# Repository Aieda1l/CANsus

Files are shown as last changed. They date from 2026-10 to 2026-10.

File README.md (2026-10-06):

# CANsus

**CANsus** ("CAN sustain") is an iterated CAN, power, and auxiliary-signal distribution PCB developed for **Newport Robotics Group (Team 948)**. The project evolved from a CAN-only terminal board into a compact, serviceable wiring hub with modular connectors, power distribution, status indication, and a documented hardware revision history.

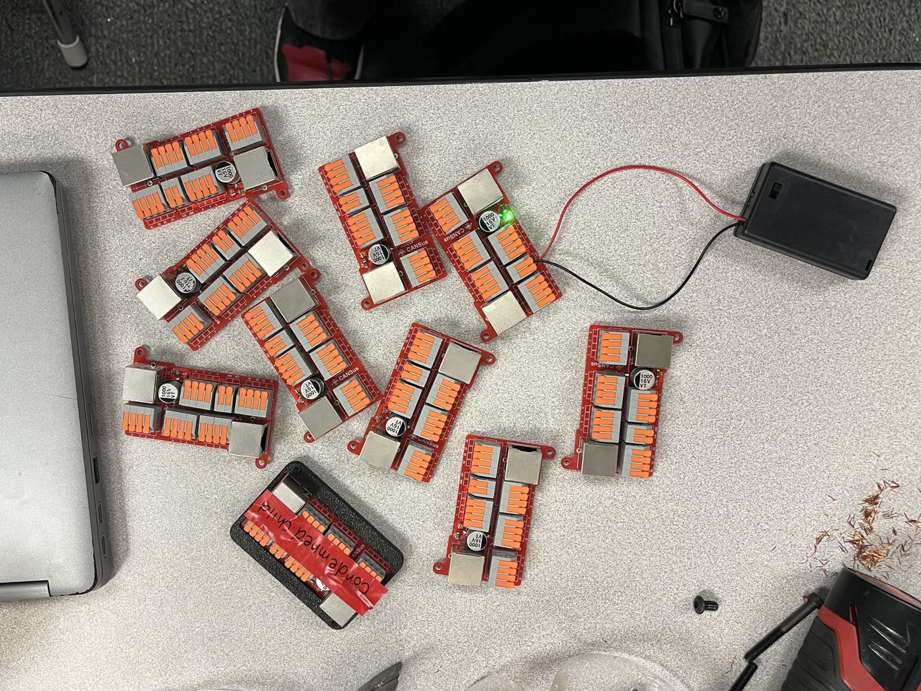
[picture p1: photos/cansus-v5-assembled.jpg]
CANsus assembled hardware


## Project overview

Robot electrical systems accumulate many point-to-point connections that must remain reliable, easy to diagnose, and practical to service under time pressure. CANsus explores a purpose-built distribution board for organizing those connections in a repeatable PCB assembly instead of relying only on loose in-line wiring.

The available KiCad history spans **v10 through v16** and shows several major design iterations: connector-family changes, board-size optimization, addition of power and auxiliary signals, migration of support components to SMD footprints, and simplification of the final interface.

This repository is intended to show not only the final hardware, but also the engineering iteration behind it.

## Engineering highlights

- **Seven documented KiCad revisions (v10-v16)** compared from the supplied design files.
- Progressed from **CAN-only distribution** to a combined **CAN + 12 V/GND + auxiliary-signal** interface.
- Added **dual RJ45 interfaces**, a bulk capacitor, and an LED status circuit beginning in v13.
- Reworked the terminal architecture in v14 from many 2-position blocks to larger **WAGO 2601-series multi-position connectors**.
- Reduced the v14 board envelope from approximately **86 × 53 mm** to **73.25 × 52.94 mm** in v15 while removing one redundant auxiliary connector — about a **14.8% reduction in width**.
- v16 simplifies the auxiliary interface from four signal nets to **two signal nets**, repurposing the remaining terminal capacity for 12 V and GND.
- The v16 layout uses **1.5 mm routing for 12 V/GND distribution** and **0.25 mm routing for CAN and auxiliary signals**.
- Physical board photos and a mechanical render document the transition from PCB design to assembled hardware.

> Revision details below are reconstructed directly from differences in the supplied KiCad schematic and PCB files. Where the files do not record the reason for a change, the documentation describes only the observed design change rather than inventing a rationale.

## Latest supplied electrical architecture — v16

The v16 design is a 2-layer, nominal 1.6 mm PCB with an Edge.Cuts envelope of approximately **73.25 × 52.94 mm**.

| Interface | Function |
|---|---|
| J1-J4 | WAGO 2601-1104 CAN distribution blocks; repeated CAN_HI / CAN_LO connections |
| J5 | WAGO 2601-1104 carrying SIGNAL_1, SIGNAL_2, 12 V, and GND |
| J7 | WAGO 2601-1102 carrying 12 V and GND |
| RJ1, RJ2 | 12 V, GND, SIGNAL_1, SIGNAL_2, CAN_HI, and CAN_LO; pins 5/6 are intentionally unconnected in v16 |
| C1 | Bulk capacitance across 12 V and GND |
| D1 + R1 | Power/status LED circuit |
| H1, H2 | #4-40 mounting holes |

The v16 RJ45 mapping visible in the PCB source is:

| Pin | Signal |
|---:|---|
| 1 | 12 V |
| 2 | GND |
| 3 | SIGNAL_1 |
| 4 | SIGNAL_2 |
| 5 | NC |
| 6 | NC |
| 7 | CAN_HI |
| 8 | CAN_LO |

## Design evolution

| Revision | Key change |
|---|---|
| **v10** | CAN-only baseline using 18 WAGO 250-202 two-position terminals and four mounting holes. |
| **v11** | Switched to WAGO 2601-3102 connectors, reduced the terminal count to 12, and narrowed the board. |
| **v12** | Reduced the CAN terminal count again to 10 and substantially compacted the board outline. |
| **v13** | Major functional expansion: added 12 V/GND, SIGNAL_1-SIGNAL_4, two RJ45 connectors, bulk capacitance, and an LED/resistor indicator circuit. |
| **v14** | Major connector/mechanical redesign: moved to 2601-1104/1102 terminal blocks, changed RJ45 footprint family, migrated the LED/resistor support circuitry to SMD footprints, and reduced mounting holes from four to two. |
| **v15** | Removed one duplicated auxiliary terminal block and reduced board width from 86 mm to 73.25 mm. |
| **v16** | Simplified the auxiliary interface to SIGNAL_1/SIGNAL_2; RJ45 pins 5/6 became NC and J5 was repurposed to include 12 V/GND. |

See [REVISION_LOG.md](REVISION_LOG.md) for the source-derived comparison and dimensional details.

## Hardware

### Assembled board

CANsus assembled hardware

The assembled-board photo shows multiple fabricated CANsus boards, lever terminals, modular connectors, the bulk capacitor, and an illuminated status LED.

### Mechanical / enclosure render

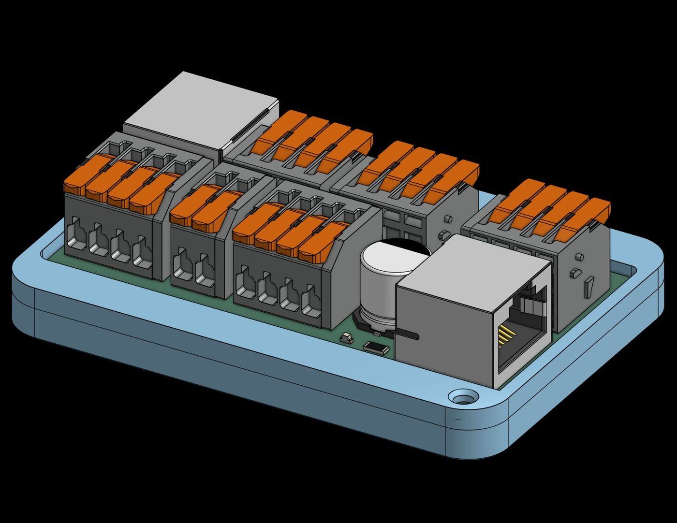
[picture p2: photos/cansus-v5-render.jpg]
CANsus render


### Earlier board

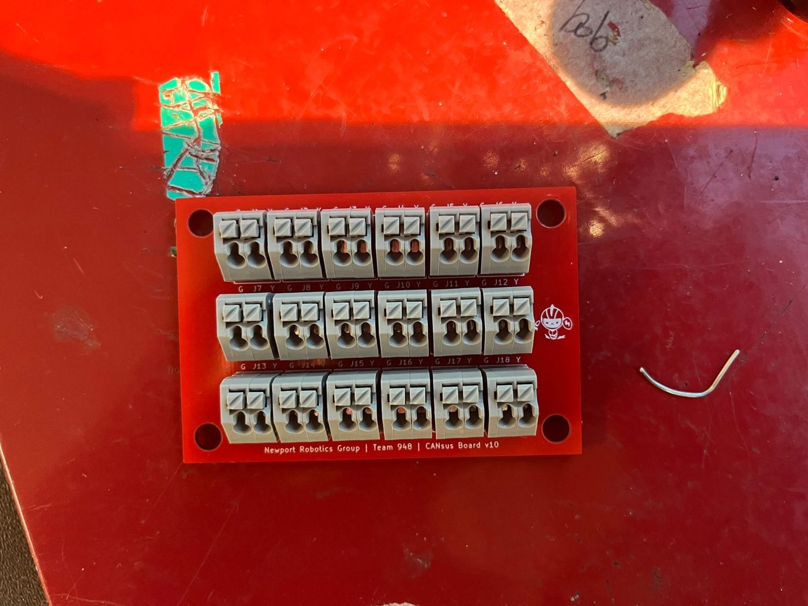
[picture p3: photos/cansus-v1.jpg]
Earlier CANsus board


The earlier photo visibly carries **CANsus Board v10** silkscreen. The photo filenames use a separate “Version 1 / Version 5” media-labeling scheme, so this repository treats the KiCad folder names (v10-v16) as the electrical design revision sequence.

## Repository contents

```text
.
├── LICENSE
├── README.md
├── REVISION_LOG.md
├── bom/
│   └── BOM.csv
├── docs/
│   ├── README.md
│   ├── cansus-board-layout.pdf
│   └── cansus-schematic.pdf
├── hardware/
│   └── kicad/
│       ├── CAN_board.kicad_pcb
│       ├── CAN_board.kicad_pro
│       ├── CAN_board.kicad_sch
│       ├── fp-lib-table
│       ├── sym-lib-table
│       └── README.md
└── photos/
    ├── cansus-v1.jpg
    ├── cansus-v5-assembled.jpg
    └── cansus-v5-render.jpg
```

## Reviewing the project

For a quick technical review:

1. Start with this README for the system architecture and design progression.
2. Read [REVISION_LOG.md](REVISION_LOG.md) for the v10-v16 hardware comparison.
3. Open the [KiCad source](hardware/kicad/) to inspect the schematic and routed PCB.
4. Review the [BOM](bom/BOM.csv) for component references.
5. Use the [PDF exports](docs/) and photos for a fast visual overview.

The browsable `hardware/kicad/` directory is the previously committed v15 source snapshot. The additional v10-v16 KiCad export set was used to reconstruct the revision history in this documentation. The supplied PDF exports also correspond to the four-signal v14/v15-era architecture; see [docs/README.md](docs/README.md).

## Tools and engineering scope represented

**KiCad 8 · schematic capture · PCB layout · connector/footprint selection · mixed through-hole/SMD design · mechanical packaging · hardware iteration · BOM/documentation · prototype assembly**

## Source notes

Some PCB 3D-model references use absolute paths from the original workstation, so a few models may be missing in KiCad's 3D viewer on another computer. The electrical schematic and PCB footprints are still embedded in the KiCad project files.

R1 is labeled simply `R` in the supplied schematic; its resistance value is therefore intentionally left unspecified in the BOM rather than guessed.

## License

Released under the [MIT License](LICENSE).

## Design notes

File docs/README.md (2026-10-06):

# PDF export notes

The PDFs in this directory are reference exports supplied with the project.

- `cansus-schematic.pdf` shows the four-auxiliary-signal architecture used by the v14/v15 design family: 12 V, GND, SIGNAL_1-SIGNAL_4, CAN_HI, CAN_LO, dual RJ45, and WAGO distribution blocks.
- `cansus-board-layout.pdf` is the accompanying PCB-layout export.

The later v16 KiCad source changes the auxiliary interface by removing SIGNAL_3 and SIGNAL_4, so these PDFs should be treated as **v14/v15-era reference exports**, not as a v16 electrical-interface definition.

For revision-by-revision differences, see [../REVISION_LOG.md](../REVISION_LOG.md).

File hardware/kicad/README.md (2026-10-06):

# KiCad source notes

The files in this directory are the **browsable v15 KiCad source snapshot** that was originally committed to the repository. A separate supplied export set containing v10-v16 was compared to build the source-derived [revision log](../../REVISION_LOG.md).

## Tool version

The supplied schematic and PCB files report **KiCad 8.0** generators.

## Files kept here

- `CAN_board.kicad_pro` — project settings
- `CAN_board.kicad_sch` — schematic
- `CAN_board.kicad_pcb` — PCB layout
- `fp-lib-table` — project footprint-library table
- `sym-lib-table` — project symbol-library table

Generated/local-state material such as `.history`, KiCad backups, `fp-info-cache`, and `.kicad_prl` is intentionally not committed.

## v15 snapshot architecture

This source snapshot contains:

- four 2601-1104 CAN distribution blocks (J1-J4)
- one 2601-1104 auxiliary block (J5) carrying SIGNAL_1-SIGNAL_4
- one 2601-1102 power block (J7) carrying 12 V/GND
- two RJ45 connectors carrying 12 V, GND, SIGNAL_1-SIGNAL_4, CAN_HI, and CAN_LO
- bulk capacitor C1
- 0603 LED D1
- 1206 resistor R1
- two #4-40 mounting holes

The later v16 export keeps the same board envelope and physical component count, but removes SIGNAL_3/SIGNAL_4 from the interface and repurposes part of J5 for 12 V/GND. See [REVISION_LOG.md](../../REVISION_LOG.md).

## Portability caveat

Some PCB 3D-model references point to absolute paths on the original designer's workstation, including local model paths for the RJ45, capacitor, and mechanical hardware. Those missing model paths do **not** change the copper or schematic source, but KiCad's 3D viewer may show missing models on another machine.

The schematic symbols and PCB footprints used by the design are embedded in the `.kicad_sch` and `.kicad_pcb` files, so the electrical/layout source remains inspectable even if an external library path is unavailable.

## Revision-label caveat

The historical folder names provide the most useful revision sequence. The PCB title blocks lag behind that sequence: v10-v13 carry a v10 title and v14-v16 carry a v14 title. The repository preserves the source as supplied rather than silently rewriting the title blocks.

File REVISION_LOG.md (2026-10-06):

# CANsus revision log

This revision history was reconstructed by comparing the supplied **KiCad v10-v16 schematic and PCB files**. The entries below document changes that are directly visible in the source: component/connector selection, net names and pin mappings, board outline, routing, and mounting features.

**Date note:** the dates shown are file-modification timestamps stored in the supplied KiCad export archive. They are useful for chronology, but they are not asserted to be formal release dates.

**Intent note:** the design files record *what changed*, not necessarily *why*. Where design intent is not explicitly encoded, this log avoids assigning a rationale.

## Summary

| Revision | Archive PCB timestamp | Edge.Cuts envelope | Main observed change |
|---|---|---:|---|
| v10 | 2024-06-05 | 76.20 × 50.80 mm | CAN-only baseline with 18 WAGO 250-202 terminal blocks |
| v11 | 2024-08-14 | 57.15 × 50.80 mm | Connector-family change to 2601-3102; terminal count reduced to 12 |
| v12 | 2024-08-16 | 63.50 × 33.02 mm | Terminal count reduced to 10; much shorter board |
| v13 | 2024-10-08 | 93.98 × 40.64 mm | Added 12 V/GND, four auxiliary signals, dual RJ45, bulk capacitor, LED/resistor |
| v14 | 2025-01-07 | 86.00 × 53.00 mm | Major connector/mechanical redesign; 2601-1104/1102 blocks, new RJ45s, SMD support parts |
| v15 | 2025-01-09 | 73.25 × 52.94 mm | Removed one auxiliary block and compacted board width |
| v16 | 2025-01-26 | 73.25 × 52.94 mm | Reduced auxiliary interface from four signals to two; repurposed J5 for power |

## v10 — CAN-only baseline

**Observed hardware**

- 18 × WAGO 250-202 two-position terminal footprints, J1-J18.
- Four mounting holes.
- Only two named electrical nets: `CAN_HI` and `CAN_LO`.
- Approximate board envelope: **76.20 × 50.80 mm**.
- Routed with 0.25 mm copper tracks in the supplied PCB.

This is the earliest KiCad snapshot in the supplied design history and matches the `CANsus Board v10` text visible on the earlier physical-board photo.

## v11 — connector-family and density change

**Changes from v10**

- Replaced the 250-202 connector family with **WAGO 2601-3102** footprints.
- Reduced the terminal population from **18 to 12** connector footprints.
- Mounting-hole footprints are represented as **#4-40 UNC** hardware in the PCB.
- Narrowed the board envelope from 76.20 mm to **57.15 mm** while retaining the 50.80 mm height.
- Electrical scope remained CAN-only: `CAN_HI` and `CAN_LO`.

## v12 — further CAN-only compaction

**Changes from v11**

- Reduced the 2601-3102 terminal population from **12 to 10**.
- Retained four #4-40 mounting holes.
- Continued to expose only `CAN_HI` and `CAN_LO`.
- Changed the board envelope to approximately **63.50 × 33.02 mm**, substantially reducing height relative to v11.

## v13 — major functional expansion

v13 is the first supplied revision that expands CANsus beyond a CAN-only distribution board.

**Added electrical functions**

- `12V`
- `GND`
- `SIGNAL_1`
- `SIGNAL_2`
- `SIGNAL_3`
- `SIGNAL_4`

**Added hardware**

- Two **SS-7188-NF RJ45** connectors, J11 and J12.
- Bulk polarized capacitor C1 between 12 V and GND.
- Through-hole LED D1 and resistor R1 as a status/power indicator circuit.
- Additional 2601-3102 terminal blocks for power and auxiliary-signal distribution.

**RJ45 mapping in v13**

| Pin | Signal |
|---:|---|
| 1 | SIGNAL_4 |
| 2 | GND |
| 3 | SIGNAL_3 |
| 4 | 12 V |
| 5 | CAN_LO |
| 6 | SIGNAL_2 |
| 7 | CAN_HI |
| 8 | SIGNAL_1 |

**Layout changes**

- Board envelope increased to approximately **93.98 × 40.64 mm** to accommodate the expanded interface.
- 12 V and GND routing uses **1.5 mm traces** in the supplied layout; CAN and signal routing remains primarily 0.25 mm.

## v14 — major architecture and packaging redesign

v14 substantially reorganizes the connector layout while retaining the expanded v13 signal set.

**Changes from v13**

- Replaced the many 2601-3102 terminal blocks with:
  - 6 × **WAGO 2601-1104** four-position blocks.
  - 1 × **WAGO 2601-1102** two-position block.
- Replaced the SS-7188-NF RJ45 footprints with **R-RJ45R08P-B000** connectors.
- Changed C1 to the `VT1C102M1010` footprint/value used in the later revisions.
- Migrated D1 from a through-hole LED footprint to **0603 SMD**.
- Migrated R1 from a through-hole resistor footprint to **1206 SMD**.
- Reduced mounting holes from **four to two** #4-40 holes.
- Board envelope became approximately **86.00 × 53.00 mm**.

**Functional grouping**

- J1-J4 provide repeated CAN_HI / CAN_LO distribution.
- J5 and J6 each duplicate SIGNAL_1-SIGNAL_4.
- J7 provides 12 V and GND.
- Both RJ45 connectors carry 12 V, GND, four auxiliary signals, CAN_HI, and CAN_LO.

**RJ45 mapping in v14**

| Pin | Signal |
|---:|---|
| 1 | 12 V |
| 2 | GND |
| 3 | SIGNAL_1 |
| 4 | SIGNAL_2 |
| 5 | SIGNAL_3 |
| 6 | SIGNAL_4 |
| 7 | CAN_HI |
| 8 | CAN_LO |

## v15 — compacted four-signal layout

**Changes from v14**

- Removed J6, one of the two duplicated 2601-1104 auxiliary-signal blocks.
- Retained J5 for SIGNAL_1-SIGNAL_4.
- Retained four 2601-1104 CAN distribution blocks, the 2601-1102 12 V/GND block, and both RJ45 connectors.
- Reduced board width from **86.00 mm to 73.25 mm**, approximately **14.8% narrower**.
- Board height remained essentially unchanged at about 52.94 mm.
- The PCB logo footprint changed to a half-size variant.
- Routing was substantially reworked; the net set and RJ45 pinout remained the same as v14.

The schematic/PCB PDF exports currently stored in `docs/` correspond to this four-auxiliary-signal architecture.

## v16 — simplified auxiliary interface

v16 keeps the v15 mechanical envelope and component count but changes the electrical assignment of the auxiliary interface.

**Changes from v15**

- Removed the named nets `SIGNAL_3` and `SIGNAL_4`.
- RJ1/RJ2 pins 5 and 6 changed from SIGNAL_3 / SIGNAL_4 to **unconnected**.
- J5 was repurposed:
  - pins 1/2: SIGNAL_1
  - pins 3/4: SIGNAL_2
  - pins 5/6: 12 V
  - pins 7/8: GND
- J7 remains a dedicated 12 V/GND connector.
- CAN distribution on J1-J4 remains unchanged.
- Board envelope remains approximately **73.25 × 52.94 mm**.
- Routing was adjusted to support the new net assignment.
- 12 V/GND continue to use 1.5 mm routing for the main distribution paths; CAN and auxiliary signal traces are 0.25 mm in the supplied PCB.

**v16 RJ45 mapping**

| Pin | Signal |
|---:|---|
| 1 | 12 V |
| 2 | GND |
| 3 | SIGNAL_1 |
| 4 | SIGNAL_2 |
| 5 | NC |
| 6 | NC |
| 7 | CAN_HI |
| 8 | CAN_LO |

## Revision-label notes

The project contains multiple forms of version labeling:

- The historical KiCad export folders are named **v10 through v16**. This log uses those folder names as the revision sequence.
- PCB title blocks are not consistently updated: v10-v13 still show `CANSus Board v10`, while v14-v16 show `CANSus Board v14`.
- The physical-photo filenames use a separate `Version 1` / `Version 5` naming scheme. The earlier photo visibly shows v10 silkscreen, so those photo names are treated as media labels rather than electrical revision numbers.

Keeping those distinctions explicit avoids rewriting the historical source or assigning unsupported mappings between the naming schemes.

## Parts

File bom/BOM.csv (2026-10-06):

Quantity | References | Value / Part | Footprint | Datasheet / Source | Notes
5 | J1, J2, J3, J4, J5 | 2601-1104 | 2601-1104:CONN4_2601-1104_WAG | 2601-1104 | WAGO four-position connector; exact manufacturer metadata not embedded beyond part number
1 | J7 | 2601-1102 | 2601-1102:CONN2_2601-1102_WAG | 2601-1102 | WAGO two-position connector; exact manufacturer metadata not embedded beyond part number
2 | RJ1, RJ2 | R-RJ45R08P-B000 | easyeda2kicad:RJ45-TH_R-RJ45R08P-B000 | https://lcsc.com/product-detail/Ethernet-Connectors-Modular-Connectors-RJ45-RJ11_Shenzhen-Cankemeng-R-RJ45R08P-B000_C386756.html | Through-hole RJ45 modular connector
1 | R1 | R | Resistor_SMD:R_1206_3216Metric | ~ | Resistance value is not specified in the supplied schematic
1 | C1 | VT1C102M1010 | easyeda2kicad:CAP-SMD_BD10.0-L10.3-W10.3-LS11.3-FD | https://lcsc.com/product-detail/Others_ROQANG-VT1C102M1010_C310843.html | Bulk capacitor as specified by schematic value
1 | D1 | LED | LED_SMD:LED_0603_1608Metric | ~ | 0603 indicator LED; color/part number not specified in the supplied schematic
2 | H1, H2 | MountingHole_#4-40_UNC_3A | MountingHole_Imperial:MountingHole_#4-40_UNC_3A | https://www.mcmaster.com/products/screws/ | Mechanical mounting holes; listed for completeness, not a purchased PCB component

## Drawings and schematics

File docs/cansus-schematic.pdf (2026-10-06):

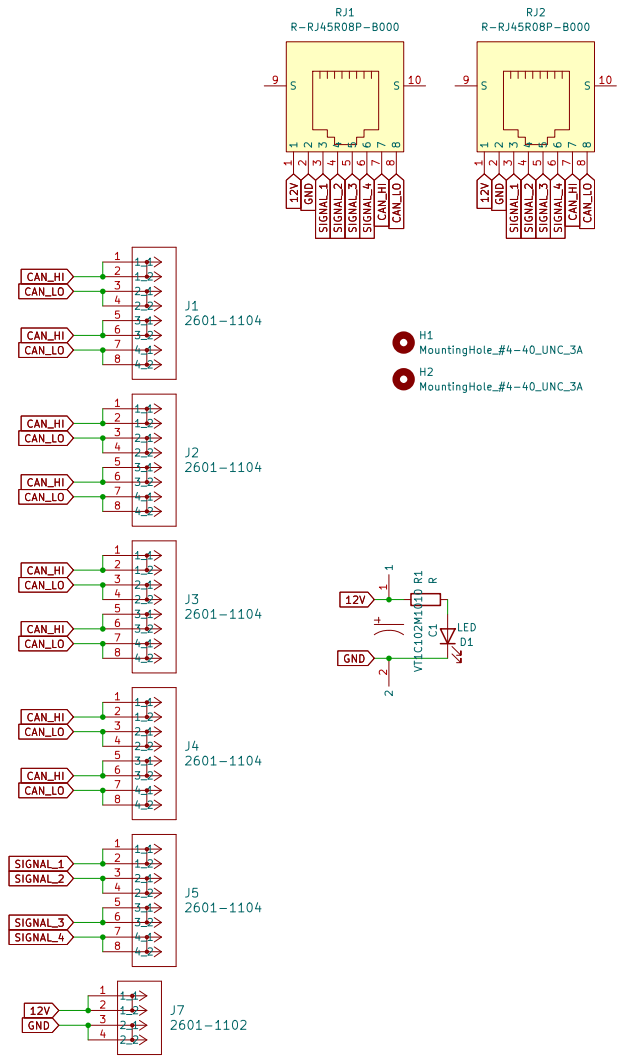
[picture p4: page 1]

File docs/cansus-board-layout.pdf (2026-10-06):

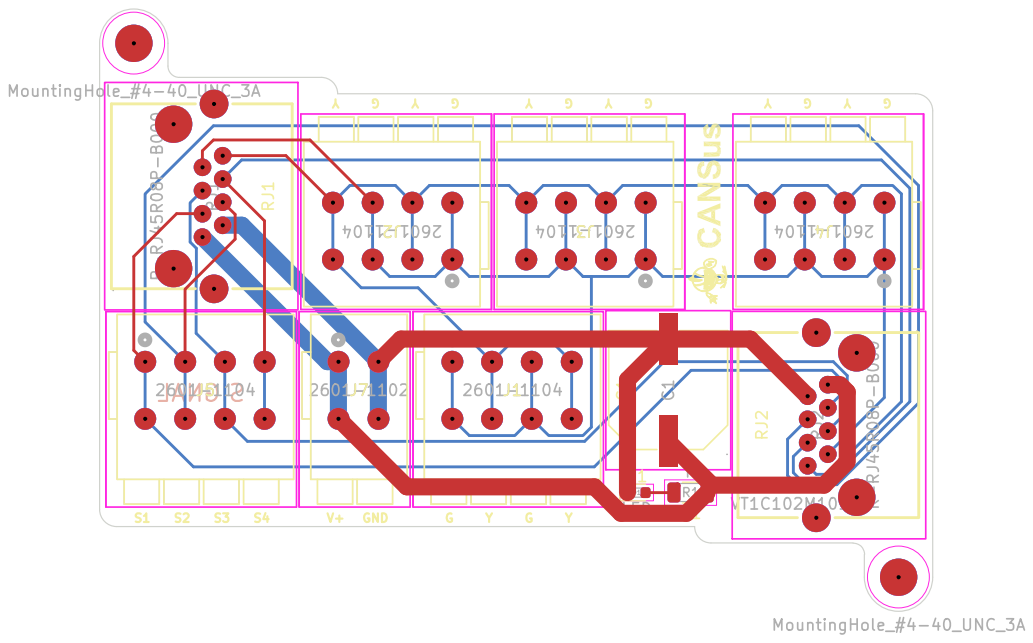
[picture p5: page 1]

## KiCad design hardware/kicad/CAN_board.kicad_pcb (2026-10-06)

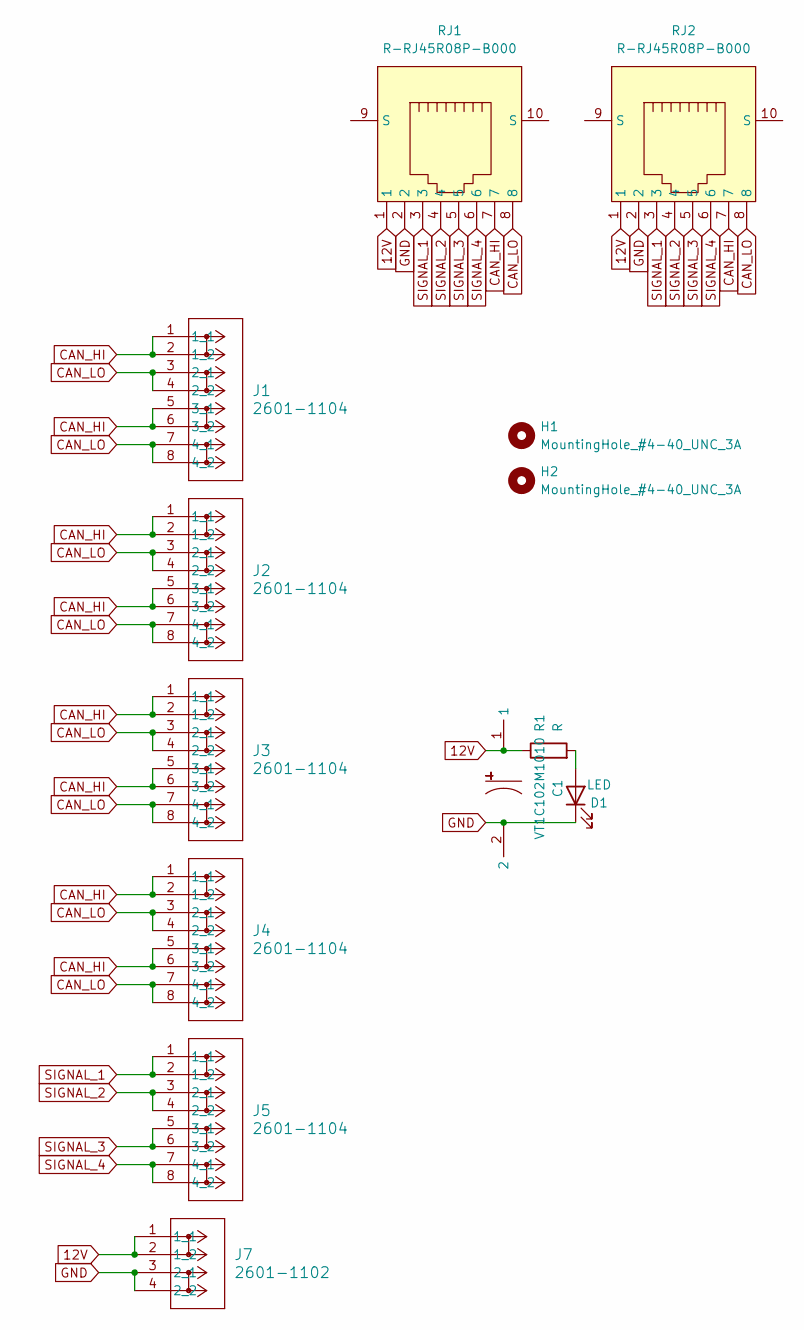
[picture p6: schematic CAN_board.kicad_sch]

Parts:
C1: VT1C102M1010; CAP-SMD_BD10.0-L10.3-W10.3-LS11.3-FD; LCSC Part C310843
D1: LED; LED_0603_1608Metric
H1, H2: MountingHole_#4-40_UNC_3A
J1, J2, J3, J4, J5: 2601-1104; CONN4_2601-1104_WAG
J7: 2601-1102; CONN2_2601-1102_WAG
R1: R; R_1206_3216Metric
RJ1, RJ2: R-RJ45R08P-B000; RJ45-TH_R-RJ45R08P-B000; LCSC Part C386756

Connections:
12V: C1.1, J7.1 (1_1), J7.2 (1_2), R1.1, RJ1.1, RJ2.1
CAN_HI: J1.1 (1_1), J1.2 (1_2), J1.5 (3_1), J1.6 (3_2), J2.1 (1_1), J2.2 (1_2), J2.5 (3_1), J2.6 (3_2), J3.1 (1_1), J3.2 (1_2), J3.5 (3_1), J3.6 (3_2), J4.1 (1_1), J4.2 (1_2), J4.5 (3_1), J4.6 (3_2), RJ1.7, RJ2.7
CAN_LO: J1.3 (2_1), J1.4 (2_2), J1.7 (4_1), J1.8 (4_2), J2.3 (2_1), J2.4 (2_2), J2.7 (4_1), J2.8 (4_2), J3.3 (2_1), J3.4 (2_2), J3.7 (4_1), J3.8 (4_2), J4.3 (2_1), J4.4 (2_2), J4.7 (4_1), J4.8 (4_2), RJ1.8, RJ2.8
GND: C1.2, D1.1 (K), J7.3 (2_1), J7.4 (2_2), RJ1.2, RJ2.2
unnamed: D1.2 (A), R1.2
SIGNAL_1: J5.1 (1_1), J5.2 (1_2), RJ1.3, RJ2.3
SIGNAL_2: J5.3 (2_1), J5.4 (2_2), RJ1.4, RJ2.4
SIGNAL_3: J5.5 (3_1), J5.6 (3_2), RJ1.5, RJ2.5
SIGNAL_4: J5.7 (4_1), J5.8 (4_2), RJ1.6, RJ2.6

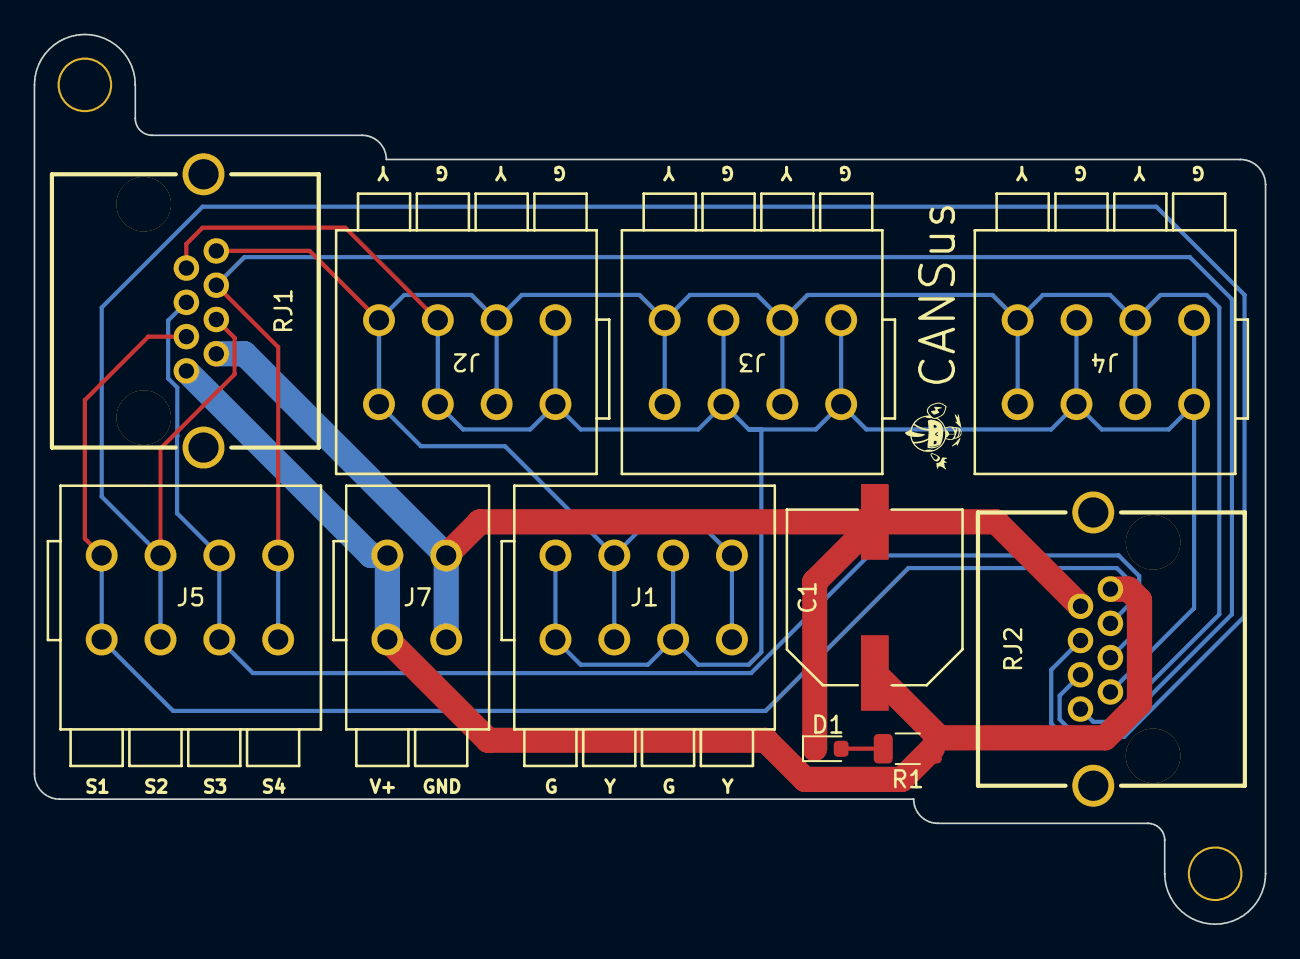
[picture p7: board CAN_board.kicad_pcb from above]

Board: 2 copper layers, 73.2 x 52.9 mm, 13 parts (0 on the bottom side), 9 nets.

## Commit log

2026-10-06 Add KiCad gitignore
2026-10-06 Add BOM from supplied schematic
    [BOM.csv]
2026-10-06 Document KiCad source portability
2026-10-06 Add CAN_board.kicad_pro from supplied KiCad project
2026-10-06 Add CAN_board.kicad_sch from supplied KiCad project
    [CAN_board.kicad_sch]
2026-10-06 Add fp-lib-table from supplied KiCad project
2026-10-06 Add sym-lib-table from supplied KiCad project
2026-10-06 Add PCB layout from supplied KiCad project
    [CAN_board.kicad_pcb]
2026-10-06 Add board photos and PDF documentation
2026-10-06 Reconstruct CANsus v10-v16 revision history from KiCad sources
2026-10-06 Clarify KiCad snapshot and revision history
